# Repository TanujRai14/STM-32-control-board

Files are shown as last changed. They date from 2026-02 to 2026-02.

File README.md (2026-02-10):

# STM32 Custom Control PCB

## Overview
This repository contains the **hardware and firmware design** for a full-fledged custom PCB based on an **STM32 microcontroller**, developed using **KiCad** for schematic & PCB design and **STM32CubeIDE** for firmware development.

The board is designed for **motor control and communication-heavy applications**, featuring support for **encoders, PWM motor drivers, I²C, UART, CAN**, and robust power and signal routing with extensive via usage and shared planes.

---

## Features

### Microcontroller
- STM32 series microcontroller (configured via STM32CubeMX)
- Optimized pin mapping for peripherals and future expansion
- SWD interface for programming and debugging

### Motor & Encoder Support
- Multiple **PWM outputs** for motor control
- **Quadrature encoder inputs** using hardware timers
- Proper timer and pin allocation to avoid peripheral conflicts

### Communication Interfaces
- **I²C** for sensors and peripherals
- **UART** for debugging, logging, or external modules
- **CAN bus** for robust industrial communication
- All interfaces routed with correct impedance, grounding, and protection considerations

### Power Management
- Dedicated power domains for logic and motor sections
- Decoupling capacitors placed close to MCU power pins
- Proper grounding strategy using shared ground planes
- Bulk capacitance for motor current transients

### PCB Design
- Designed in **KiCad**
- Multi-layer PCB with:
  - Ground and power planes
  - Extensive via stitching for EMI reduction
  - Proper trace width calculation for high-current paths
- Clear separation between noisy (motor) and sensitive (MCU/communication) sections

---

## Repository Structure

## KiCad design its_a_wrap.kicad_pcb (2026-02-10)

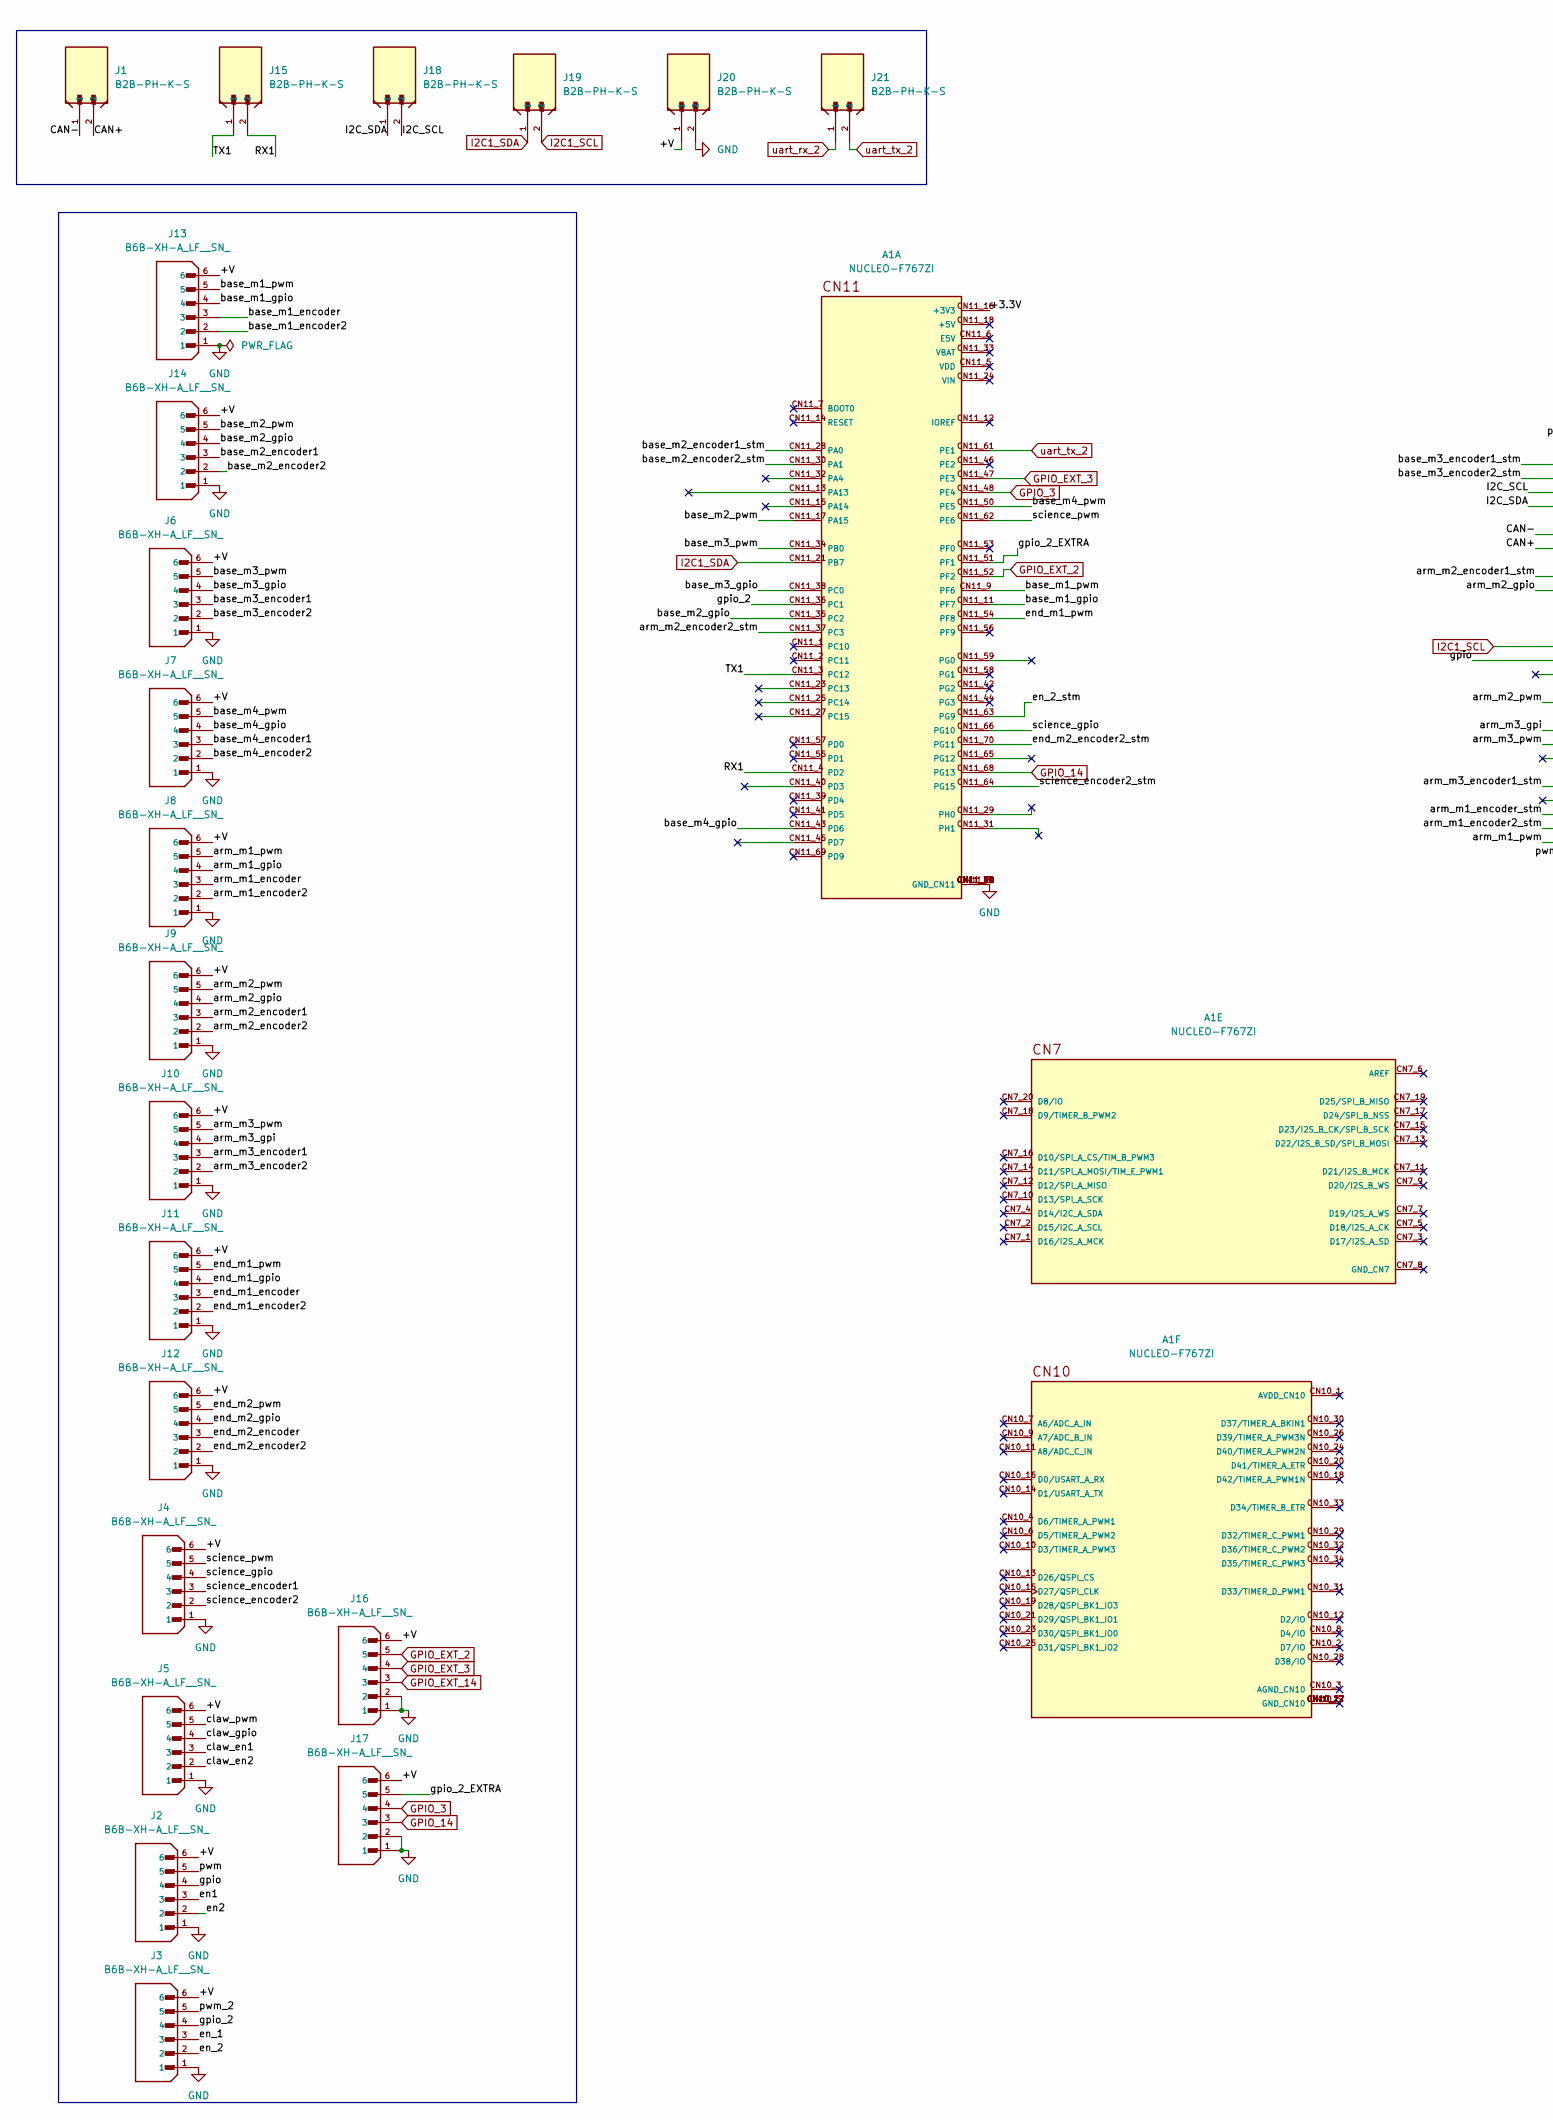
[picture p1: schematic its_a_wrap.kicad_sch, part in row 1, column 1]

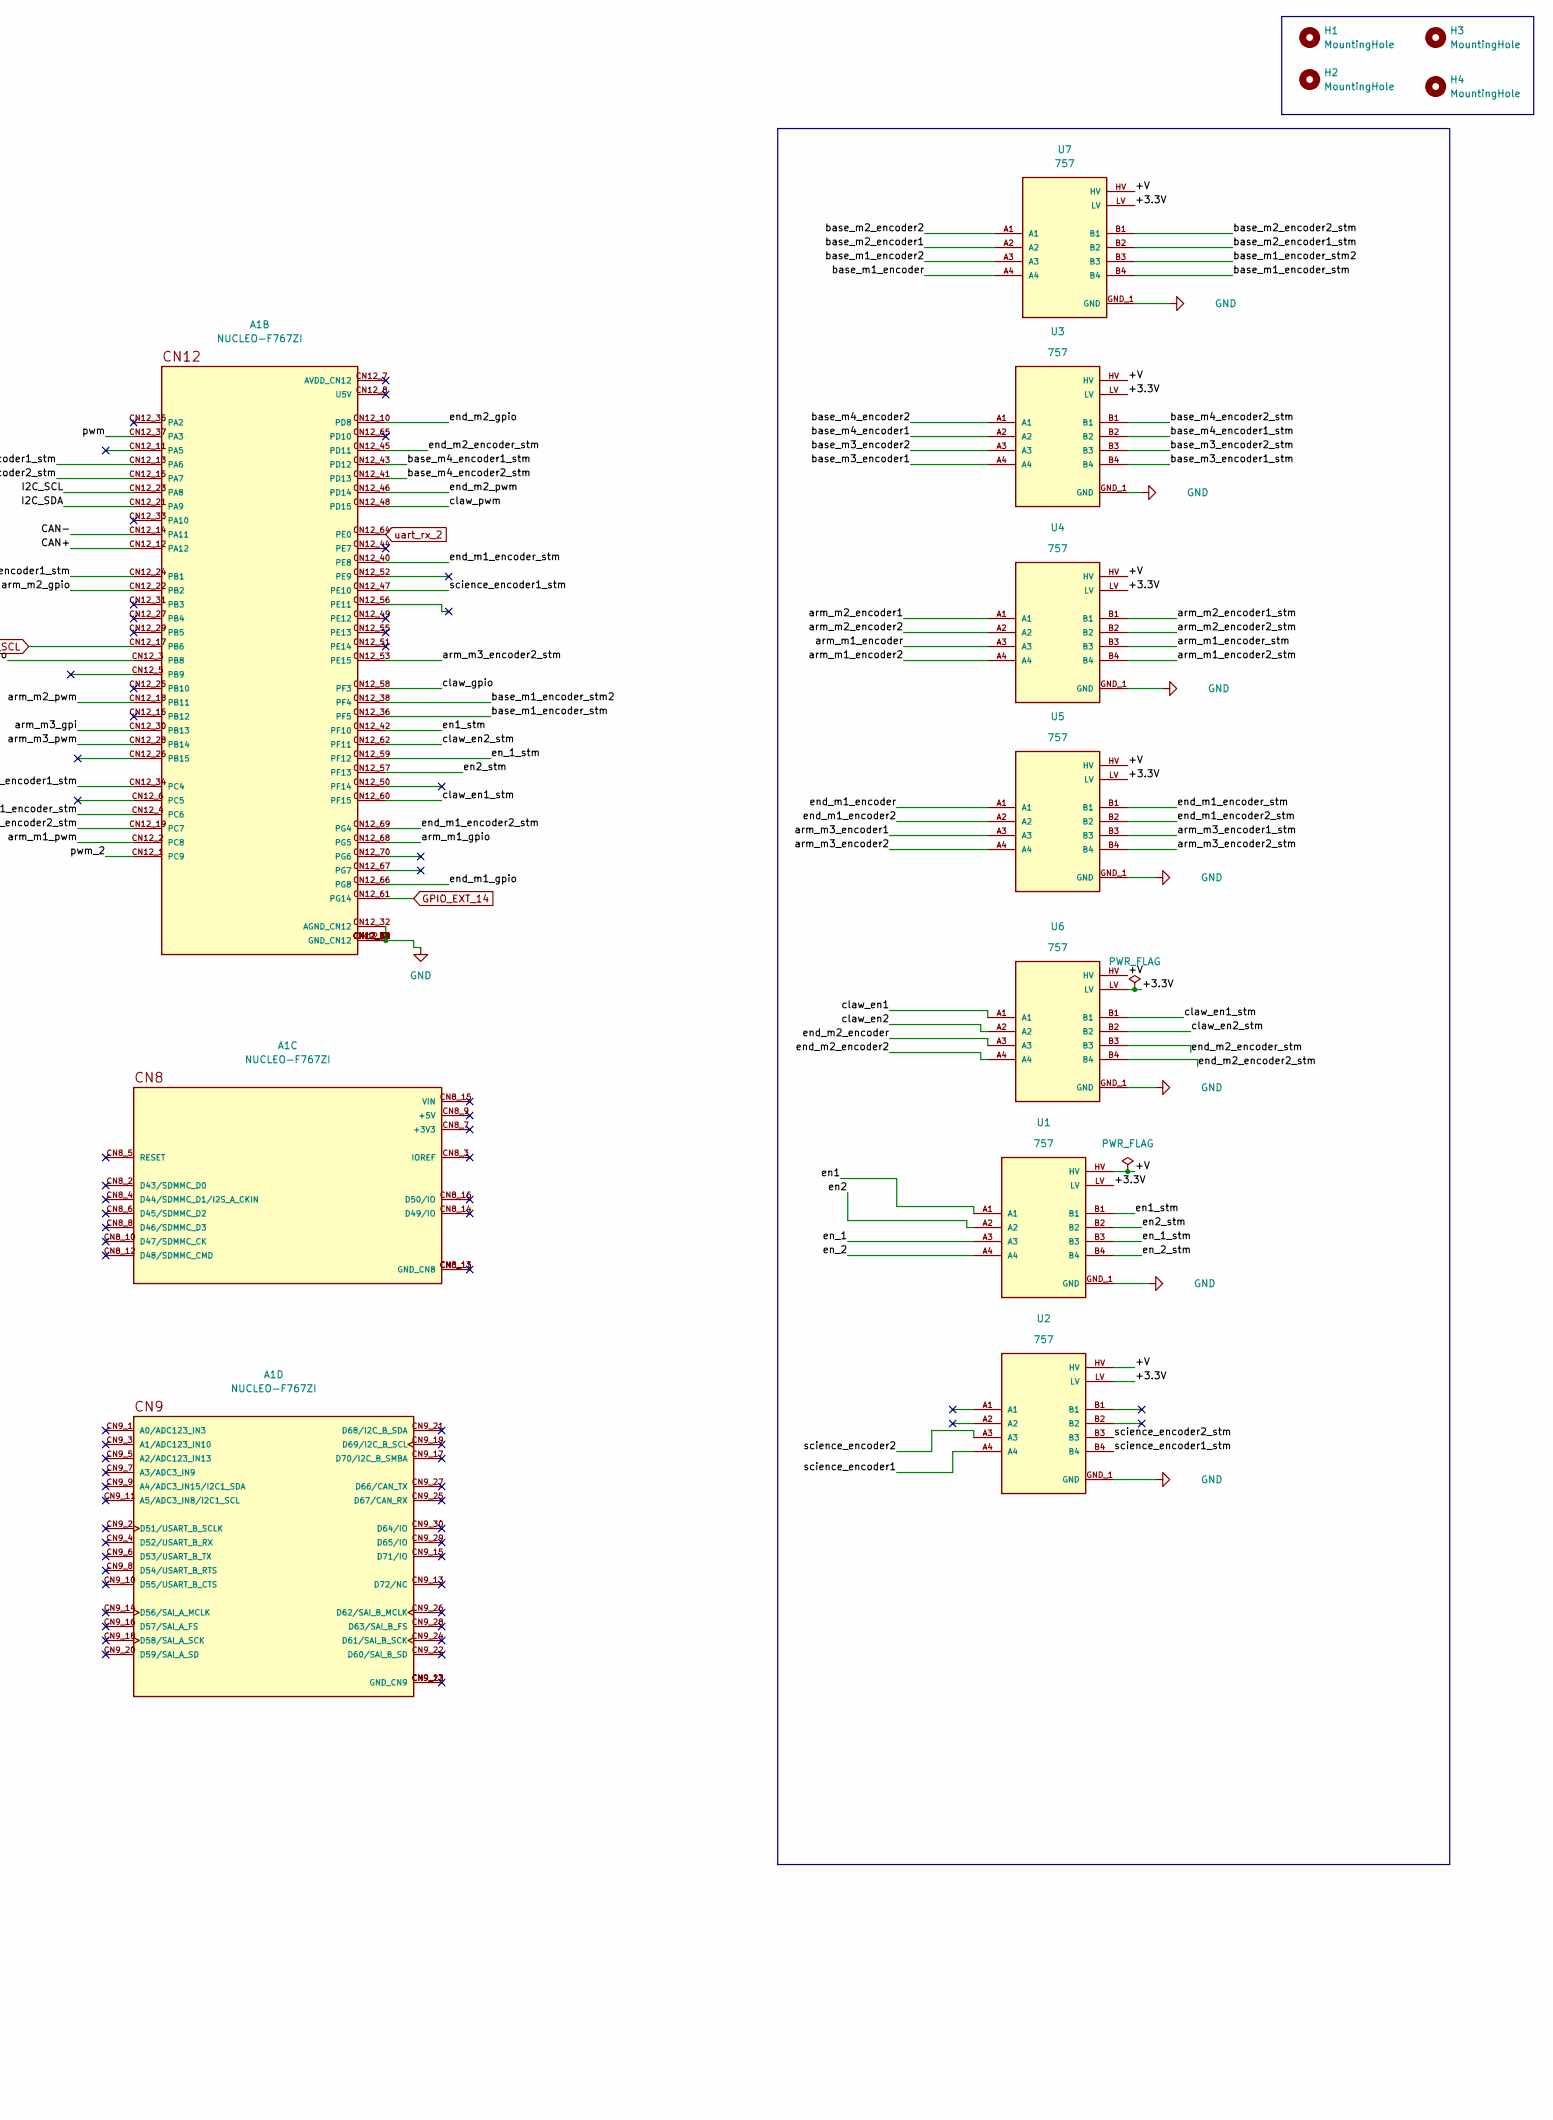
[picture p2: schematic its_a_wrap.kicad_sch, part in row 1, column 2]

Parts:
A1: NUCLEO-F767ZI; ST_NUCLEO-F767ZI; PARTREV 7
H1, H2, H3, H4: MountingHole; MountingHole_3.2mm_M3
J1, J15, J18, J19, J20, J21: B2B-PH-K-S; JST_B2B-PH-K-S
J2, J3, J4, J5, J6, J7, J8, J9, J10, J11, J12, J13, J14, J16, J17: B6B-XH-A_LF__SN_; JST_B6B-XH-A_LF__SN_; PARTREV 7/4/21
U1, U2, U3, U4, U5, U6, U7: 757; MODULE_757; PARTREV N/A

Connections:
/+3.3V: A1.CN11_16 (+3V3), U1.LV, U2.LV, U3.LV, U4.LV, U5.LV, U6.LV, U7.LV
/+V: J2.6, J3.6, J4.6, J5.6, J6.6, J7.6, J8.6, J9.6, J10.6, J11.6, J12.6, J13.6, J14.6, J16.6, J17.6, J20.1, U1.HV, U2.HV, U3.HV, U4.HV, U5.HV, U6.HV, U7.HV
/CAN+: A1.CN12_12 (PA12), J1.2
/CAN-: A1.CN12_14 (PA11), J1.1
/I2C_SCL: A1.CN12_23 (PA8), J18.2
/I2C_SDA: A1.CN12_21 (PA9), J18.1
/RX1: A1.CN11_4 (PD2), J15.2
/TX1: A1.CN11_3 (PC12), J15.1
/arm_m1_encoder: J8.3, U4.A3
/arm_m1_encoder2: J8.2, U4.A4
/arm_m1_encoder2_stm: A1.CN12_19 (PC7), U4.B4
/arm_m1_encoder_stm: A1.CN12_4 (PC6), U4.B3
/arm_m1_gpio: A1.CN12_68 (PG5), J8.4
/arm_m1_pwm: A1.CN12_2 (PC8), J8.5
/arm_m2_encoder1: J9.3, U4.A1
/arm_m2_encoder1_stm: A1.CN12_24 (PB1), U4.B1
/arm_m2_encoder2: J9.2, U4.A2
/arm_m2_encoder2_stm: A1.CN11_37 (PC3), U4.B2
/arm_m2_gpio: A1.CN12_22 (PB2), J9.4
/arm_m2_pwm: A1.CN12_18 (PB11), J9.5
/arm_m3_encoder1: J10.3, U5.A3
/arm_m3_encoder1_stm: A1.CN12_34 (PC4), U5.B3
/arm_m3_encoder2: J10.2, U5.A4
/arm_m3_encoder2_stm: A1.CN12_53 (PE15), U5.B4
/arm_m3_gpi: A1.CN12_30 (PB13), J10.4
/arm_m3_pwm: A1.CN12_28 (PB14), J10.5
/base_m1_encoder: J13.3, U7.A4
/base_m1_encoder2: J13.2, U7.A3
/base_m1_encoder_stm: A1.CN12_36 (PF5), U7.B4
/base_m1_encoder_stm2: A1.CN12_38 (PF4), U7.B3
/base_m1_gpio: A1.CN11_11 (PF7), J13.4
/base_m1_pwm: A1.CN11_9 (PF6), J13.5
/base_m2_encoder1: J14.3, U7.A2
/base_m2_encoder1_stm: A1.CN11_28 (PA0), U7.B2
/base_m2_encoder2: J14.2, U7.A1
/base_m2_encoder2_stm: A1.CN11_30 (PA1), U7.B1
/base_m2_gpio: A1.CN11_35 (PC2), J14.4
/base_m2_pwm: A1.CN11_17 (PA15), J14.5
/base_m3_encoder1: J6.3, U3.A4
/base_m3_encoder1_stm: A1.CN12_13 (PA6), U3.B4
/base_m3_encoder2: J6.2, U3.A3
/base_m3_encoder2_stm: A1.CN12_15 (PA7), U3.B3
/base_m3_gpio: A1.CN11_38 (PC0), J6.4
/base_m3_pwm: A1.CN11_34 (PB0), J6.5
/base_m4_encoder1: J7.3, U3.A2
/base_m4_encoder1_stm: A1.CN12_43 (PD12), U3.B2
/base_m4_encoder2: J7.2, U3.A1
/base_m4_encoder2_stm: A1.CN12_41 (PD13), U3.B1
/base_m4_gpio: A1.CN11_43 (PD6), J7.4
/base_m4_pwm: A1.CN11_50 (PE5), J7.5
/claw_en1: J5.3, U6.A1
/claw_en1_stm: A1.CN12_60 (PF15), U6.B1
/claw_en2: J5.2, U6.A2
/claw_en2_stm: A1.CN12_62 (PF11), U6.B2
/claw_gpio: A1.CN12_58 (PF3), J5.4
/claw_pwm: A1.CN12_48 (PD15), J5.5
/en1: J2.3, U1.A1
/en1_stm: A1.CN12_42 (PF10), U1.B1
/en2: J2.2, U1.A2
/en2_stm: A1.CN12_57 (PF13), U1.B2
/en_1: J3.3, U1.A3
/en_1_stm: A1.CN12_59 (PF12), U1.B3
/en_2: J3.2, U1.A4
/en_2_stm: A1.CN11_63 (PG9), U1.B4
/end_m1_encoder: J11.3, U5.A1
/end_m1_encoder2: J11.2, U5.A2
/end_m1_encoder2_stm: A1.CN12_69 (PG4), U5.B2
/end_m1_encoder_stm: A1.CN12_40 (PE8), U5.B1
/end_m1_gpio: A1.CN12_66 (PG8), J11.4
/end_m1_pwm: A1.CN11_54 (PF8), J11.5
/end_m2_encoder: J12.3, U6.A3
/end_m2_encoder2: J12.2, U6.A4
/end_m2_encoder2_stm: A1.CN11_70 (PG11), U6.B4
/end_m2_encoder_stm: A1.CN12_45 (PD11), U6.B3
/end_m2_gpio: A1.CN12_10 (PD8), J12.4
/end_m2_pwm: A1.CN12_46 (PD14), J12.5
/gpio: A1.CN12_3 (PB8), J2.4
/gpio_2: A1.CN11_36 (PC1), J3.4
/gpio_2_EXTRA: A1.CN11_51 (PF1), J17.5
/pwm: A1.CN12_37 (PA3), J2.5
/pwm_2: A1.CN12_1 (PC9), J3.5
/science_encoder1: J4.3, U2.A4
/science_encoder1_stm: A1.CN12_47 (PE10), U2.B4
/science_encoder2: J4.2, U2.A3
/science_encoder2_stm: A1.CN11_64 (PG15), U2.B3
/science_gpio: A1.CN11_66 (PG10), J4.4
/science_pwm: A1.CN11_62 (PE6), J4.5
GND: A1.CN11_8 (GND_CN11), A1.CN11_19 (GND_CN11), A1.CN11_20 (GND_CN11), A1.CN11_22 (GND_CN11), A1.CN11_49 (GND_CN11), A1.CN11_60 (GND_CN11), A1.CN11_71 (GND_CN11), A1.CN11_72 (GND_CN11), A1.CN12_9 (GND_CN12), A1.CN12_20 (GND_CN12), A1.CN12_32 (AGND_CN12), A1.CN12_39 (GND_CN12), A1.CN12_54 (GND_CN12), A1.CN12_63 (GND_CN12), A1.CN12_71 (GND_CN12), A1.CN12_72 (GND_CN12), J2.1, J3.1, J4.1, J5.1, J6.1, J7.1, J8.1, J9.1, J10.1, J11.1, J12.1, J13.1, J14.1, J16.1, J16.2, J17.1, J17.2, J20.2, U1.GND_1 (GND), U1.GND_2 (GND), U2.GND_1 (GND), U2.GND_2 (GND), U3.GND_1 (GND), U3.GND_2 (GND), U4.GND_1 (GND), U4.GND_2 (GND), U5.GND_1 (GND), U5.GND_2 (GND), U6.GND_1 (GND), U6.GND_2 (GND), U7.GND_1 (GND), U7.GND_2 (GND)
GPIO_3: A1.CN11_48 (PE4), J17.4
GPIO_14: A1.CN11_68 (PG13), J17.3
GPIO_EXT_2: A1.CN11_52 (PF2), J16.5
GPIO_EXT_3: A1.CN11_47 (PE3), J16.4
GPIO_EXT_14: A1.CN12_61 (PG14), J16.3
I2C1_SCL: A1.CN12_17 (PB6), J19.2
I2C1_SDA: A1.CN11_21 (PB7), J19.1
uart_rx_2: A1.CN12_64 (PE0), J21.1
uart_tx_2: A1.CN11_61 (PE1), J21.2

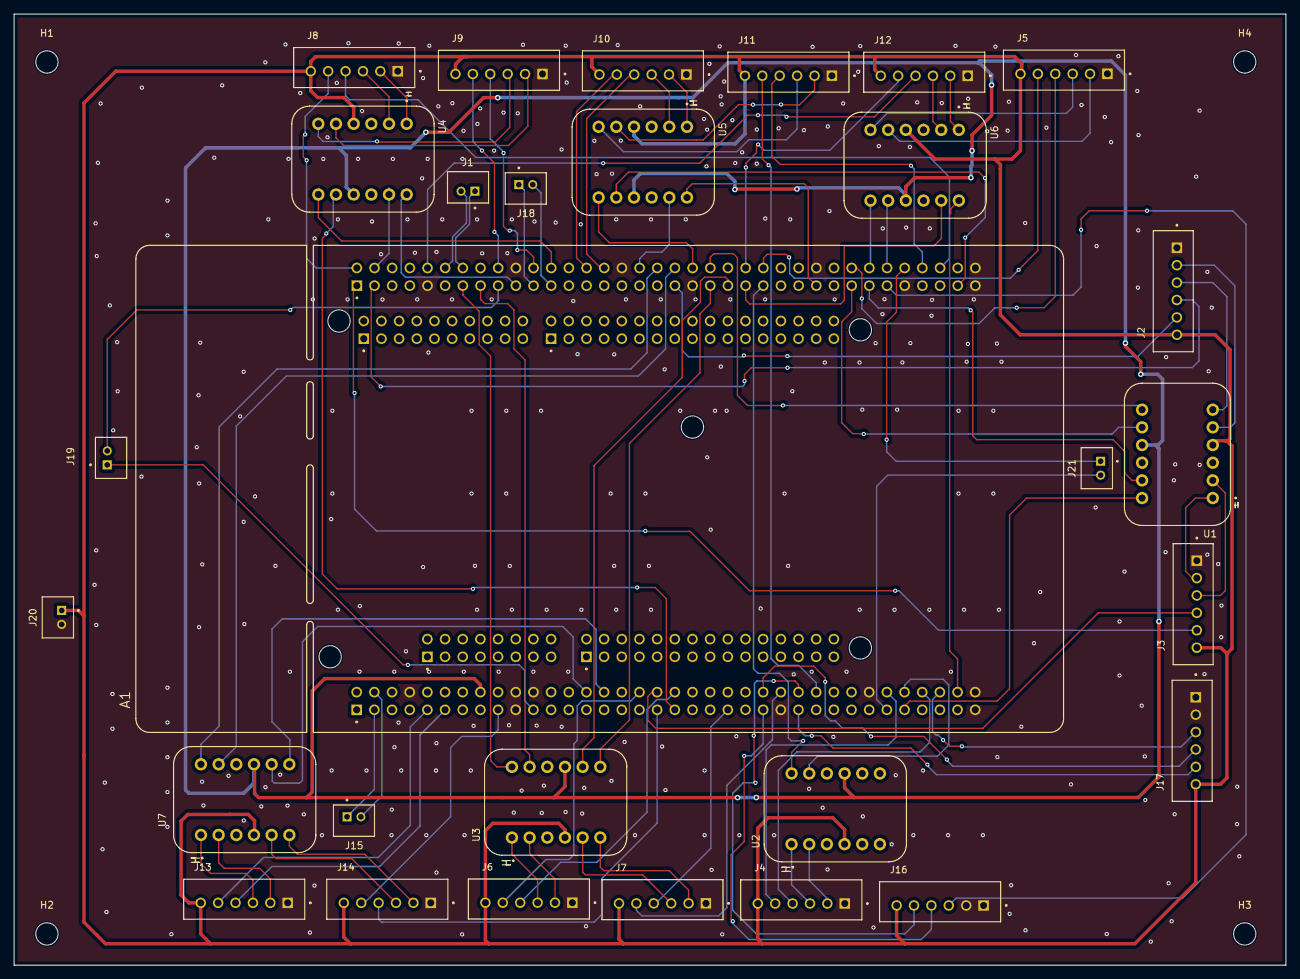
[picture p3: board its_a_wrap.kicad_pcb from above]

Board: 2 copper layers, 182.8 x 136.7 mm, 33 parts (0 on the bottom side), 97 nets.
